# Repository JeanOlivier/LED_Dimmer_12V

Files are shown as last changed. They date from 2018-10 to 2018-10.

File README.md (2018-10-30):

# LED DIMMER 12V

A pulse width modulation (PWM) LED Dimmer built around a 555 timer.
Designed for 12V+ power supply (but should work for 5V+) and using a CMOS transistor to support high power draw.

The 555 part is inspired by [this circuit](http://www.pcbheaven.com/circuitpages/LED_PWM_Dimmer/).

## Circuit

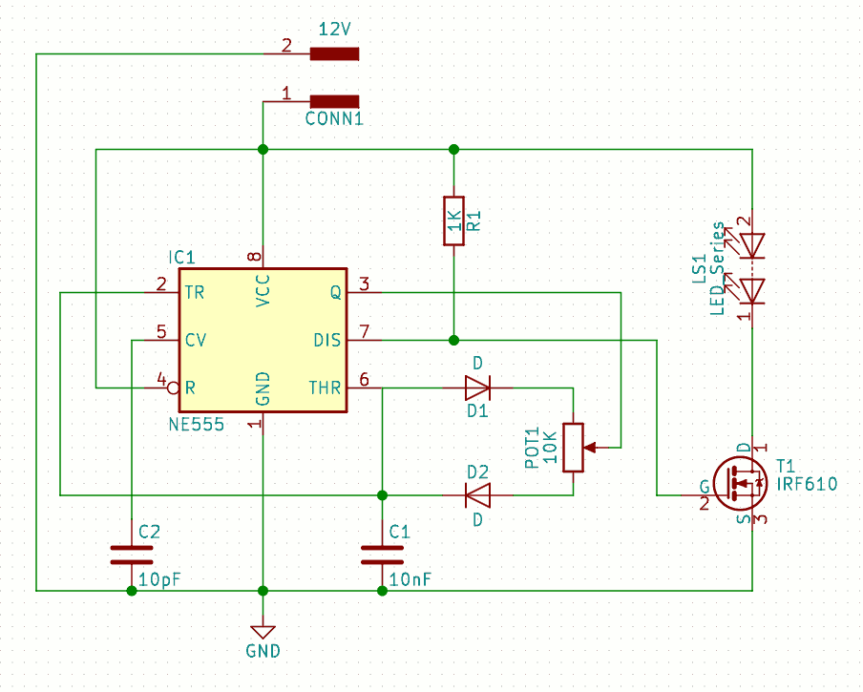
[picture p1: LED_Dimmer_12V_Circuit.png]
Circuit


## Parts
- C1 is mandatory and should be small, 10nF works fine
- R1 should be as low a possible without drawing too much current from the 555. Higher values might limit the maximum brightness. R1 of 1k‎Ω to 10kΩ work fine.
- C2 is optional but it's cleaner to use it.
- Pot1 should be 10kΩ.

## Caveats
- At low brightness, the circuit is unstable. You need to turn the potentiometer a little before the leds light up. It's not smooth 0-100 duty cycle. I'm not sure how to improve this without using a very low R1 and risk frying the 555.
- At low brightness, R1 can heat quite a lot, use a properly power rated resitor.

## 3D Render of v1.1

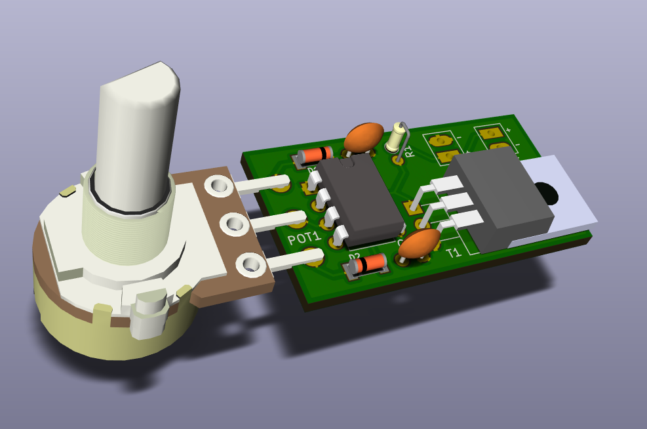
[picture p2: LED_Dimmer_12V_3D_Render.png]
3D Render of v1.1


## Picture of v1.0, with corrections applied to behave like v1.1

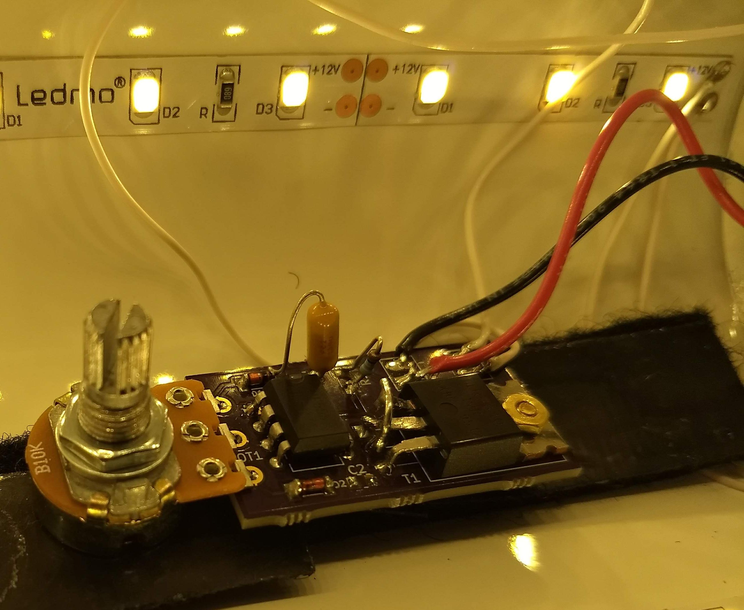
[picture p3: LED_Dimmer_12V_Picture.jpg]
Picture of v1.0 with corrections applied


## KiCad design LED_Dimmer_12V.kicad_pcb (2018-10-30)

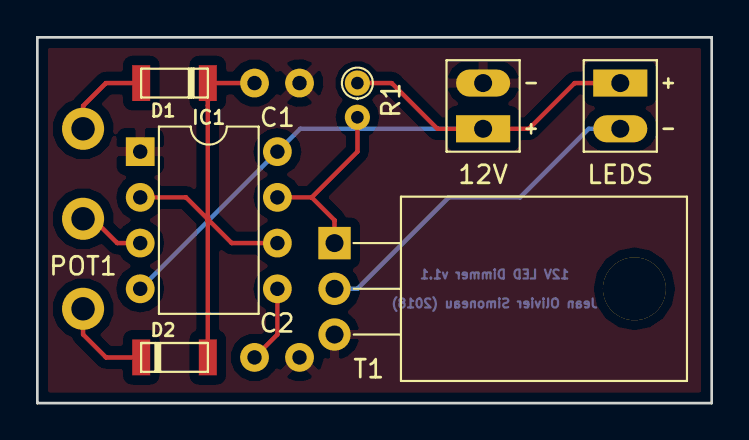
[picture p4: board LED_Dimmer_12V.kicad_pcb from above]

Board: 2 copper layers, 37.5 x 20.3 mm, 10 parts (0 on the bottom side), 9 nets.

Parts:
12V: 12V; PINHEAD1-2
C1: 10nF; C_Disc_D5.0mm_W2.5mm_P2.50mm
C2: 10pF; C_Disc_D5.0mm_W2.5mm_P2.50mm
D1, D2: D; sod80c
IC1: NE555; DIP-8_W7.62mm
LEDS: LED_Series; PINHEAD1-2
POT1: 10K; Potentiometer_Alps_RK163_Single_Vertical
R1: 10K; R_Axial_DIN0204_L3.6mm_D1.6mm_P1.90mm_Vertical
T1: IRF610; TO-220_Horizontal

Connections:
GND: 12V.2, C1.2, C2.2, IC1.1, T1.3
unnamed: C1.1, D1.2, D2.1, IC1.2, IC1.6
unnamed: C2.1, IC1.5
unnamed: 12V.1, IC1.4, IC1.8, LEDS.2, R1.1
unnamed: D1.1, POT1.1
unnamed: D2.2, POT1.3
unnamed: IC1.3, POT1.2
unnamed: IC1.7, R1.2, T1.2
unnamed: LEDS.1, T1.1

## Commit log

2018-10-26 Added a missing trace
    [LED_Dimmer_12V.kicad_pcb]
2018-10-26 Corrected IRF610 footprint (swapped G and D; pads 1&2)
    [LED_Dimmer_12V.kicad_pcb]
2018-10-30 v1.2, THT footprints for R1 and Cs. Updated README with 3D render and picture of first populated PCB.
    [LED_Dimmer_12V.kicad_pcb, LED_Dimmer_12V.sch]
2018-10-30 Added circuit to README
    [LED_Dimmer_12V.kicad_pcb]
